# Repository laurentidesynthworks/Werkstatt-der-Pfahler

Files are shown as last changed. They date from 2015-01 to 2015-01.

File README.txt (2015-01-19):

The Werkstatt der Pfähler (Werkstatt the Impaler) is a Moog Werkstatt-Ø1 that has been cut up and extensively modified. There 
is a huge beast inside these little synths that can only be accessed through modifying.

There are 2 versions available: Standard and Full. The Standard version is perfect for incorporating into an existing Eurorack 
modular system. Most of the header patch points have been brought to the rear of the unit to 3.5mm Jacks. Most importantly, 
the EG can be triggered by an external gate. This is not possible without modification.  

The Full version takes the standard and brings it to a stand-alone powerhouse! In addition to the CV In’s and Out’s at the 
rear, buffers are added to all CV Out’s (these are circuits that keep critical voltages, like the raw VCO waveforms from 
sagging when used to drive external gear).  The CV Out’s are wired to TRS jacks, giving a total of 8 individual outputs. 
A MIDI 2 CV (MINICV) converter is added to drive the VCO and EG. Additionally, the CV & Gate generated by the MIDI 2 CV is 
brought to 2 jacks, so when the Werkstatt is not in use, it can be used to drive other analog gear that does not have MIDI,
but does have CV & Gate In’s. A mixer is added to give volume control over the Werkstatt VCO and External Audio. Additionally, 
the VCF is wired to the Audio In jack, so when nothing is plugged into the jack, the Audio In volume knob will send the VCF 
back into itself for some intense filter overdrive! A 2nd glide circuit is added in line with the VCO CV In. The Werkstatt 
Glide potentiometer is removed and replaced with a dual gang potentiometer. This way one knob can control both the Werkstatt 
glide and the external pitch glide. The VCO Wave selector switch is removed and a mixer circuit is added so the 2 waveforms 
can be continuously blended from one to the other. Lastly, there is a Fine Tune knob added.

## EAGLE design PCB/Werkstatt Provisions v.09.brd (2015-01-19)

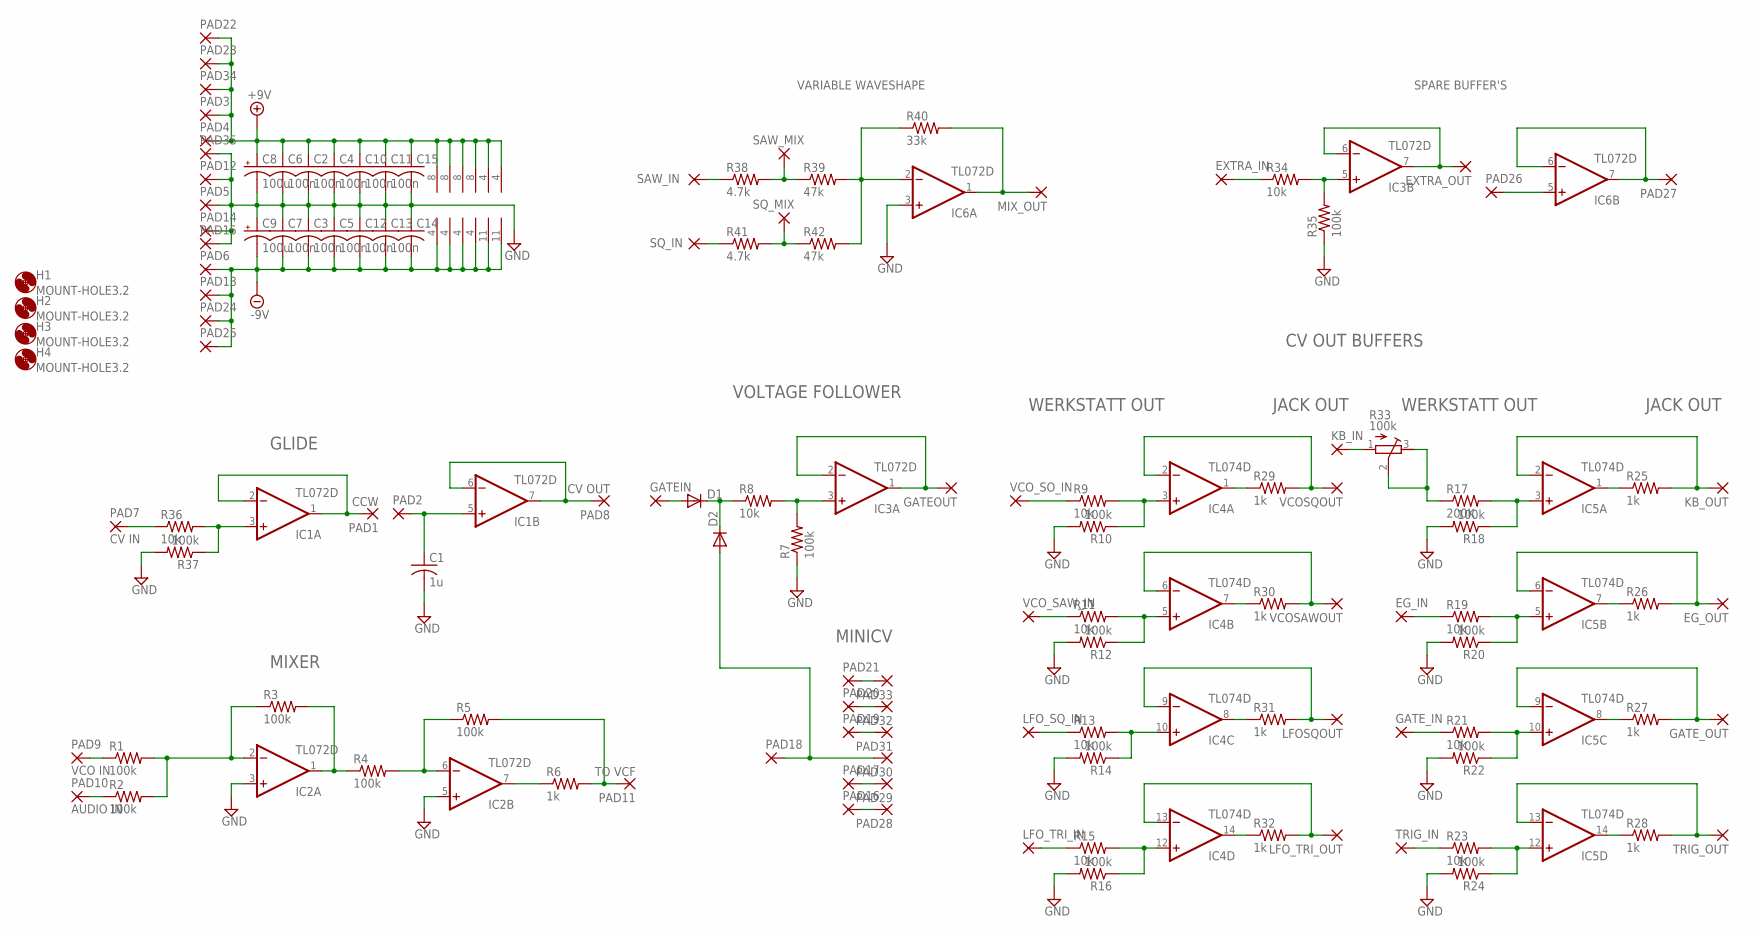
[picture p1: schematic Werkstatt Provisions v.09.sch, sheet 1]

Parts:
C1: 1u; C0805K
C2, C3, C4, C5, C6, C7, C10, C11, C12, C13: 100n; C0805K
C8, C9: 100u; PANASONIC_D
C14, C15: C-USC0805; C0805
D1, D2: DIODE-SOD323-W; SOD323-W
EG_IN: 2,0/0,9-O
EG_OUT: 2,0/0,9-O
EXTRA_IN: 2,0/0,9-O
EXTRA_OUT: 2,0/0,9-O
GATEIN: 2,0/0,9-O
GATEOUT: 2,0/0,9-O
GATE_IN: 2,0/0,9-O
GATE_OUT: 2,0/0,9-O
H1, H2, H3, H4: MOUNT-HOLE3.2; 3,2
IC1, IC2, IC3, IC6: TL072D; SO08
IC4, IC5: TL074D; SO14
KB_IN: 2,0/0,9-O
KB_OUT: 2,0/0,9-O
LFOSQOUT: 2,0/0,9-O
LFO_SQ_IN: 2,0/0,9-O
LFO_TRI_IN: 2,0/0,9-O
LFO_TRI_OUT: 2,0/0,9-O
MIX_OUT: 2,0/0,9-O
PAD1: CCW; 2,0/0,9-O
PAD2, PAD3, PAD4, PAD5, PAD6, PAD12, PAD13, PAD14, PAD15, PAD16, PAD17, PAD18, PAD19, PAD20, PAD21, PAD22, PAD23, PAD24, PAD25, PAD26, PAD27: 2,0/0,9-O
PAD7: CV IN; 2,0/0,9-O
PAD8: CV OUT; 2,0/0,9-O
PAD9: VCO IN; 2,0/0,9-O
PAD10: AUDIO IN; 2,0/0,9-O
PAD11: TO VCF; 2,0/0,9-O
PAD28, PAD29, PAD30, PAD31, PAD32, PAD33, PAD34, PAD35: 1,6/0,8
R1, R2, R3, R4, R5, R7, R10, R12, R14, R16, R18, R20, R22, R24, R35, R37: 100k; M0805
R6, R25, R26, R27, R28, R29, R30, R31, R32: 1k; M0805
R8, R9, R11, R13, R15, R19, R21, R23, R34, R36: 10k; M0805
R17: 200K; M0805
R33: 100k; RTRIM3202
R38, R41: 4.7k; R0805
R39, R42: 47k; R0805
R40: 33k; R0805
SAW_IN: 2,0/0,9-O
SAW_MIX: 2,0/0,9-O
SQ_IN: 2,0/0,9-O
SQ_MIX: 2,0/0,9-O
TRIG_IN: 2,0/0,9-O
TRIG_OUT: 2,0/0,9-O
VCOSAWOUT: 2,0/0,9-O
VCOSQOUT: 2,0/0,9-O
VCO_SAW_IN: 2,0/0,9-O
VCO_SO_IN: 2,0/0,9-O

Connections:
+9V: C2.1, C4.1, C6.1, C8.+, C10.1, C11.1, C15.1, IC1.8 (V+), IC2.8 (V+), IC3.8 (V+), IC4.4 (V+), IC5.4 (V+), IC6.8 (V+), PAD3.1, PAD4.1, PAD22.1, PAD23.1, PAD34.1
-9V: C3.2, C5.2, C7.2, C9.-, C12.2, C13.2, C14.2, IC1.4 (V-), IC2.4 (V-), IC3.4 (V-), IC4.11 (V-), IC5.11 (V-), IC6.4 (V-), PAD6.1, PAD13.1, PAD24.1, PAD25.1
GATE_IN_MIDI: D2.A, PAD18.1, PAD30.1
GND: C1.2, C2.2, C3.1, C4.2, C5.1, C6.2, C7.1, C8.-, C9.+, C10.2, C11.2, C12.1, C13.1, C14.1, C15.2, IC2.3 (+IN), IC2.5 (+IN), IC6.3 (+IN), PAD5.1, PAD12.1, PAD14.1, PAD15.1, PAD35.1, R7.1, R10.2, R12.2, R14.2, R16.2, R18.2, R20.2, R22.2, R24.2, R35.1, R37.2
LSW: D1.A, GATEIN.1
unnamed: IC1.1 (OUT), IC1.2 (-IN), PAD1.1
unnamed: PAD7.1, R36.1
unnamed: C1.1, IC1.5 (+IN), PAD2.1
unnamed: IC1.6 (-IN), IC1.7 (OUT), PAD8.1
unnamed: IC2.2 (-IN), R1.2, R2.2, R3.1
unnamed: PAD16.1, PAD28.1
unnamed: IC2.1 (OUT), R3.2, R4.1
unnamed: IC2.6 (-IN), R4.2, R5.1
unnamed: PAD11.1, R5.2, R6.2
unnamed: IC2.7 (OUT), R6.1
unnamed: PAD9.1, R1.1
unnamed: PAD10.1, R2.1
unnamed: IC3.5 (+IN), R34.2, R35.2
unnamed: IC3.3 (+IN), R7.2, R8.2
unnamed: PAD17.1, PAD29.1
unnamed: GATEOUT.1, IC3.1 (OUT), IC3.2 (-IN)
unnamed: PAD19.1, PAD31.1
unnamed: PAD20.1, PAD32.1
unnamed: PAD21.1, PAD33.1
unnamed: D1.C, D2.C, R8.1
unnamed: IC1.3 (+IN), R36.2, R37.1
unnamed: R9.1, VCO_SO_IN.1
unnamed: IC4.3 (+IN), R9.2, R10.1
unnamed: EG_IN.1, R19.1
unnamed: R11.1, VCO_SAW_IN.1
unnamed: IC4.5 (+IN), R11.2, R12.1
unnamed: IC4.2 (-IN), R29.2, VCOSQOUT.1
unnamed: IC4.6 (-IN), R30.2, VCOSAWOUT.1
unnamed: IC4.9 (-IN), LFOSQOUT.1, R31.2
unnamed: IC4.13 (-IN), LFO_TRI_OUT.1, R32.2
unnamed: IC5.2 (-IN), KB_OUT.1, R25.2
unnamed: EG_OUT.1, IC5.6 (-IN), R26.2
unnamed: GATE_OUT.1, IC5.9 (-IN), R27.2
unnamed: IC5.13 (-IN), R28.2, TRIG_OUT.1
unnamed: LFO_TRI_IN.1, R15.1
unnamed: IC4.14 (OUT), R32.1
unnamed: LFO_SQ_IN.1, R13.1
unnamed: IC4.10 (+IN), R13.2, R14.1
unnamed: IC4.12 (+IN), R15.2, R16.1
unnamed: IC4.8 (OUT), R31.1
unnamed: IC4.1 (OUT), R29.1
unnamed: IC4.7 (OUT), R30.1
unnamed: IC5.5 (+IN), R19.2, R20.1
unnamed: IC5.10 (+IN), R21.2, R22.1
unnamed: GATE_IN.1, R21.1
unnamed: R23.1, TRIG_IN.1
unnamed: R17.1, R33.2 (S), R33.3 (A)
unnamed: IC5.3 (+IN), R17.2, R18.1
unnamed: IC5.12 (+IN), R23.2, R24.1
unnamed: IC5.14 (OUT), R28.1
unnamed: IC5.8 (OUT), R27.1
unnamed: IC5.7 (OUT), R26.1
unnamed: IC5.1 (OUT), R25.1
unnamed: KB_IN.1, R33.1 (E)
unnamed: EXTRA_IN.1, R34.1
unnamed: IC6.2 (-IN), R39.2, R40.1, R42.2
unnamed: EXTRA_OUT.1, IC3.6 (-IN), IC3.7 (OUT)
unnamed: R41.2, R42.1, SQ_MIX.1
unnamed: R41.1, SQ_IN.1
unnamed: R38.2, R39.1, SAW_MIX.1
unnamed: R38.1, SAW_IN.1
unnamed: IC6.1 (OUT), MIX_OUT.1, R40.2
unnamed: IC6.6 (-IN), IC6.7 (OUT), PAD27.1
unnamed: IC6.5 (+IN), PAD26.1

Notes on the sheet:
GLIDE
MIXER
VOLTAGE FOLLOWER
CV OUT BUFFERS
WERKSTATT OUT
JACK OUT
MINICV
SPARE BUFFER'S
VARIABLE WAVESHAPE

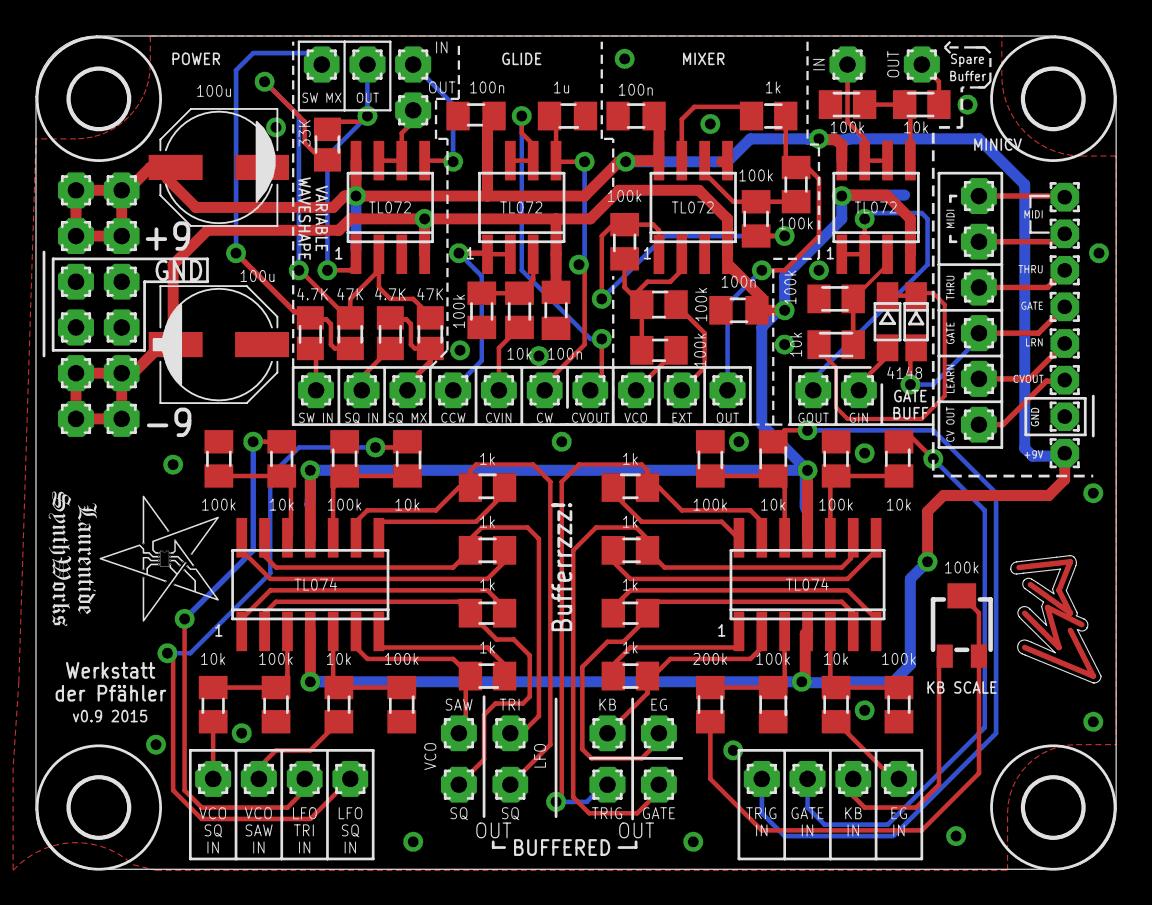
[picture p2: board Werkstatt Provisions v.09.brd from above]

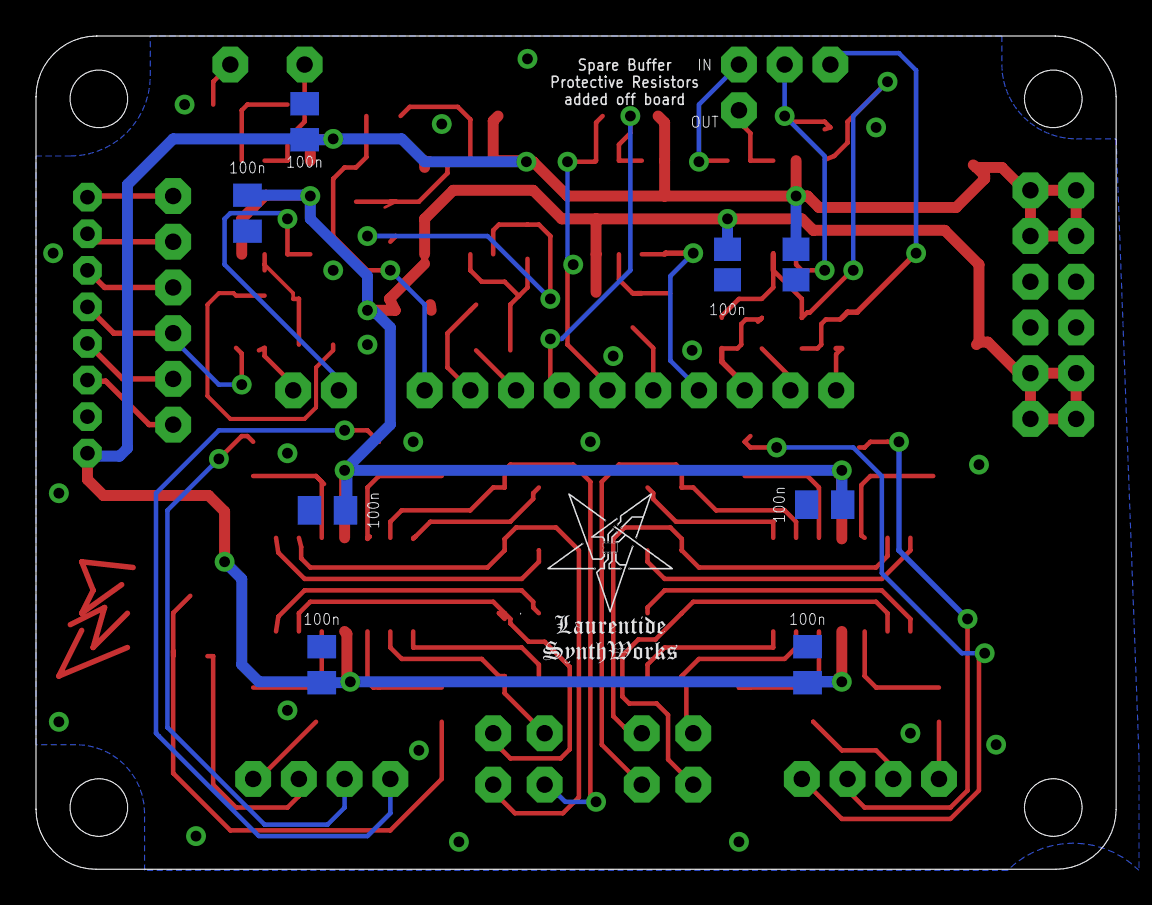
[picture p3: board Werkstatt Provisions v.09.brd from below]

Board: 2 copper layers, 60.0 x 46.3 mm, 129 parts (8 on the bottom side), 69 nets.
